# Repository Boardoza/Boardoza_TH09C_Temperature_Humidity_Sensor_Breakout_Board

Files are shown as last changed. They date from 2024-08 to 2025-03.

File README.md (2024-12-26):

# Boardoza TH09C Temperature Humidity Sensor Breakout Board
The TH09C Digital Temperature and Humidity Sensor Breakout Board offers reliable environmental monitoring with high accuracy and low power consumption. Featuring the TH09C sensor, this board provides precise digital temperature and humidity readings via an I<sup>2</sup>C interface. Its fast response time and high repeatability make it ideal for use in HVAC systems, weather stations, and other applications where environmental data is critical. 

### [Click here to purchase!](https://www.ozdisan.com/maker-and-iot-products/boardoza/boardoza-modules/BOARDOZA-TH09C/1206510)

|Front Side|Back Side|
|:---:|:---:|
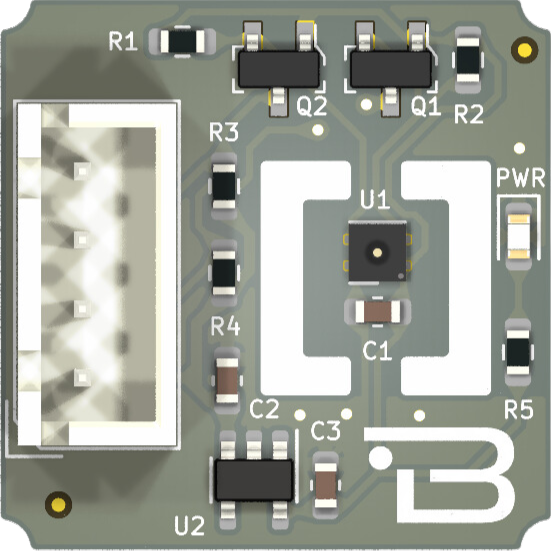
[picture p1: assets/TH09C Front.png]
TH09C Front
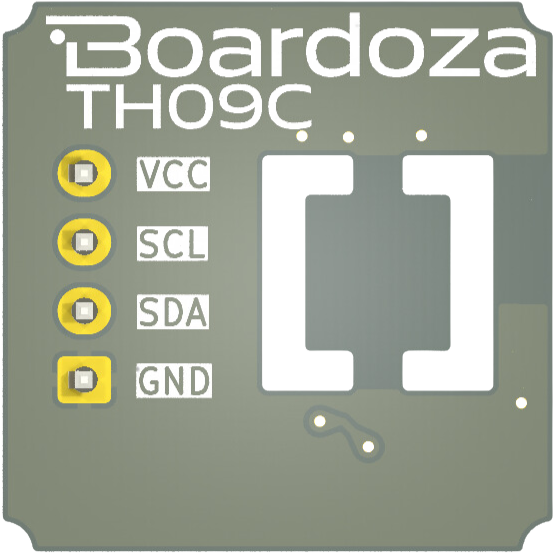
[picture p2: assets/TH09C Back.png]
TH09C Back
| | |

---
## Key Features
- Ultra-Accurate Sensing: Temperature sensor with ±0.15°C accuracy and relative humidity sensor with typical ±2.0%RH accuracy.
- Wide Sensing Range: Supports temperature measurement from –40°C to 100°C and humidity from 0% to 100%.
- Digital Output: Provides digital temperature and humidity readings via TTL I2C interface for easy integration.
- Low Power Consumption: Optimized for battery-operated devices with minimal energy usage.
-Compact Design: Small form factor suitable for a wide range of environmental monitoring applications.

---

## Technical Specifications

**Input Voltage:**	2V - 5.5V

**Voltage Input Type:**	Molex 4 pin 2.50mm header

**Interface:** I<sup>2</sup>C  

**Functions:**	Temprature and Humidity Sensor

**Temperature Accuracy:** ±0.15°C  

**Humidity Accuracy:** Typical ±2.0% RH  

**Measurement Range:**	 -40°C ~ +100°C

**Operating Humidity:** 0% to 100% RH  

**Operating Temperature:**	-40°C ~ +100°C

**Board Dimensions:**	20mm x 20mm

---
## Board Pinout
| (J1) Pin Number | Pin Name | Description |
|:---:|:---:| --- |
| 1 | VCC | Power Supply |
| 2 | SCL | I<sup>2</sup>C Serial Clock Pin |
| 3 | SDA | I<sup>2</sup>C Serial Data Pin|
| 4 | GND | Ground|

---
## Board Dimensions

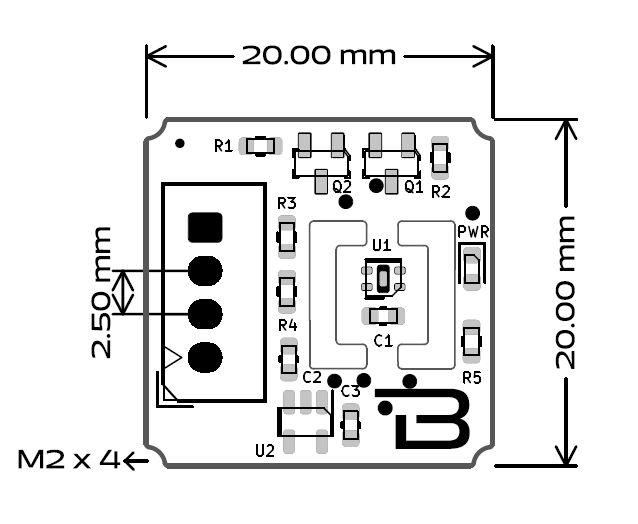
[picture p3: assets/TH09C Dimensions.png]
TH09C Dimension


---
## Step Files

[Boardoza TH09C.step]( ./assets/TH09C%20Step.step)

---
## Datasheet

[Boardoza TH09C Datasheet.pdf](./assets/TH09C%20Datasheet.pdf)

---
## Version History
- V1.0.0 - Initial Release

---
## Support
- If you have any questions or need support, please contact support@boardoza.com

---
## License

Shield: [][cc-by-sa]

This work is licensed under a [Creative Commons Attribution-ShareAlike 4.0 International License][cc-by-sa].

[][cc-by-sa]

[cc-by-sa]: http://creativecommons.org/licenses/by-sa/4.0/
[cc-by-sa-image]: https://licensebuttons.net/l/by-sa/4.0/88x31.png
[cc-by-sa-shield]: https://img.shields.io/badge/License-CC%20BY--SA%204.0-lightgrey.svg

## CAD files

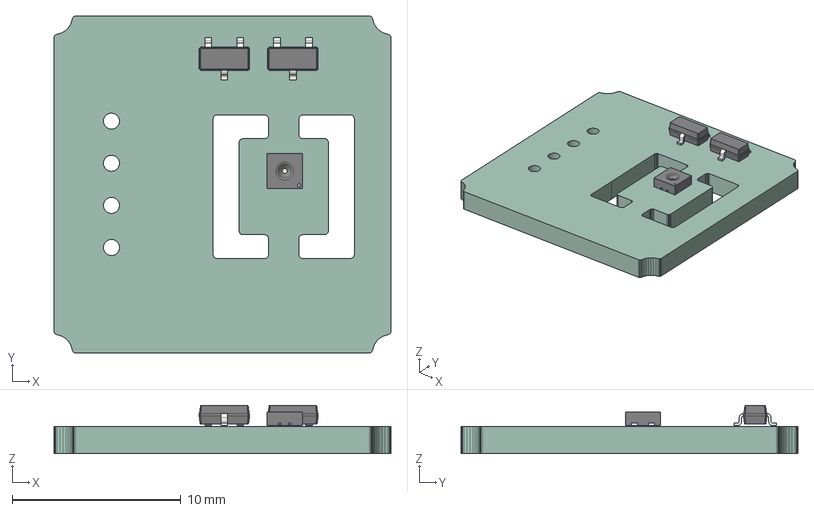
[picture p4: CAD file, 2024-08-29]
assets/TH09C Step.step
20.0 x 20.0 x 2.85 mm
SHTC3
SOT_23 x 2
_autosave-TH09C_TEMP_SENSOR PCB

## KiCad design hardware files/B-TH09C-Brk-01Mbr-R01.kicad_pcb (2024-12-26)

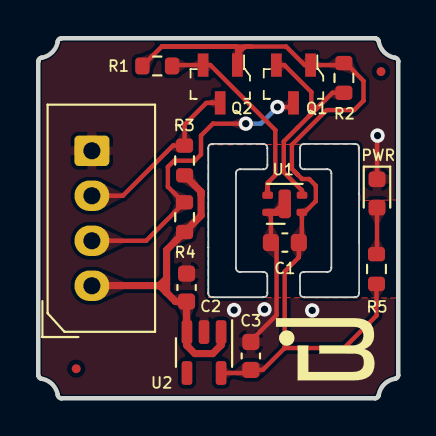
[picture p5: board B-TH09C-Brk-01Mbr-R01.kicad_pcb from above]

Board: 2 copper layers, 20.0 x 20.0 mm, 14 parts (0 on the bottom side), 8 nets.

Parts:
C1: 100nF; C_0603_1608Metric
C2, C3: 1uF; C_0603_1608Metric
J1: MOLEX_CONNECTOR_1X4; 2317-04S_1x04_P2.50mm_Vertical
PWR: LED POWER; LED_0603_1608Metric
Q1, Q2: 2N7002_R1_00001; SOT-23-3
R1, R2, R3, R4, R5: 10K; R_0603_1608Metric
U1: TH09C
U2: TLV73333PDBVR; SOT-23-5

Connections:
+3V3: C1.1, C3.1, Q1.1 (G), Q2.1 (G), R1.1, R2.1, R5.1, U1.1 (VDD), U2.5 (OUT)
GND: C1.2, C2.2, C3.2, J1.4, PWR.1 (K), U1.4 (VSS), U1.5 (NC), U2.2 (GND)
unnamed: PWR.2 (A), R5.2
unnamed: Q1.2 (S), R2.2, U1.2 (SCL)
unnamed: Q2.2 (S), R1.2, U1.3 (SDA)
SCL: J1.2, Q1.3 (D), R4.2
SDA: J1.3, Q2.3 (D), R3.2
VCC: C2.1, J1.1, R3.1, R4.1, U2.1 (IN), U2.3 (EN)

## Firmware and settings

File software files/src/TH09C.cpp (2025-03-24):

/*!
 *  @file TH09C.cpp
 *
 *  @mainpage TH09C is a low cost temperature/humidity sensor.
 *
 *  @section intro_sec Introduction
 *
 *  This is a library for Boardoza TH09C low cost temperature/humidity sensors.
 *
 *  @section author Author
 *
 *  Written by Boardoza.
 *
 *  @section license License
 *
 *  MIT license, all text above must be included in any redistribution
 */


#include "TH09C.h"
#include <Arduino.h>

/** @brief begin
*          Starts the I2C connection and setup sensor pins.
* @param frequency I2C speed in KHz.
*/ 

TH09C::TH09C() {

}

void TH09C::begin() {
  Wire.begin();  // Setting I2C speed.
  delay(100);

  uint8_t TH09_Ctrl = readByteOneReg(TH09_Address, SYS_CTRL);
  if (!TH09_Ctrl) {
    uint8_t TH09_Low_Power = 0;  // Failed to read control register, low power mode inactive
  } else {
    while (writeByteOneReg(TH09_Address, SYS_CTRL, 0x00) != 0) {
      // Activating low power mode, waiting until the process is complete...
    }
    uint8_t TH09_Low_Power = 1;  // Low power mode successfully activated
  }

  uint8_t TH09_Status = readByteOneReg(TH09_Address, SYS_STAT);

  uint8_t TH09_SensRun = readByteOneReg(TH09_Address, SENS_RUN);
  if (!TH09_SensRun) {
    while (writeByteOneReg(TH09_Address, SENS_RUN, 0x03) != 0) {
      // Activating the sensor, waiting until the activation process is complete...
    }
  }
  
  uint8_t TH09_SensStart = readByteOneReg(TH09_Address, SENS_START);
  if (!TH09_SensStart) {
    while (writeByteOneReg(TH09_Address, SENS_START, 0x03) != 0) {
      // Initializing the sensor, waiting until initialization is complete...
    }
  }
}

/**
 * @brief Reads the temperature and humidity values from the TH09 sensor.
 *
 * This function reads the temperature and humidity values from the TH09 sensor
 * using the `readMultiBytesOneReg` function. It converts the raw temperature value
 * from Fahrenheit to Celsius and calculates the relative humidity as a percentage.
 * The results are stored in the `temperature` and `humidity` variables passed by reference.
 *
 * @param temperature Reference to a float variable to store the temperature in Celsius.
 * @param humidity Reference to a float variable to store the relative humidity in percentage.
 */


void TH09C::readTempHum(float& temperature, float& humidity) {
  uint8_t TH09_Temp_Array[2];
  readMultiBytesOneReg(TH09_Address, T_VAL, TH09_Temp_Array, 2);

  float TH09_Temp =  TH09_Temp_Array[1] << 8 | TH09_Temp_Array[0];
  TH09_Temp = (TH09_Temp) / 64;            // Fahrenheit to Kelvin   
  temperature = TH09_Temp - 273.15;        // Kelvin to Celsius

  uint8_t TH09_Hum_Array[2];
  readMultiBytesOneReg(TH09_Address, H_VAL, TH09_Hum_Array, 2);
  uint16_t TH09_Hum = TH09_Hum_Array[1] << 8 | TH09_Hum_Array[0];
  humidity = (float)TH09_Hum / 512;        // Relative humidity (in %)
}

/**
 * @brief Reads the temperature value from the TH09 sensor.
 *
 * This function reads the temperature value from the TH09 sensor
 * using the `readMultiBytesOneReg` function. It converts the raw temperature value
 * from Fahrenheit to Celsius.
 * The results are stored in the `temperature` and variables passed by reference.
 *
 * @param temperature Reference to a float variable to store the temperature in Celsius.
 */

void TH09C::readTemp(float& temperature) {
  uint8_t TH09_Temp_Array[2];
  readMultiBytesOneReg(TH09_Address, T_VAL, TH09_Temp_Array, 2);

  float TH09_Temp =  TH09_Temp_Array[1] << 8 | TH09_Temp_Array[0];
  TH09_Temp = (TH09_Temp) / 64;            // Fahrenheit to Kelvin   
  temperature = TH09_Temp - 273.15;        // Kelvin to Celsius
}

/**
 * @brief Reads the humidity value from the TH09 sensor.
 *
 * This function reads the humidity value from the TH09 sensor
 * using the `readMultiBytesOneReg` function. It calculates the relative humidity as a percentage.
 * The results are stored in the `temperature` and `humidity` variables passed by reference.
 *
 * @param temperature Reference to a float variable to store the temperature in Celsius.
 */

void TH09C::readHum(float& humidity) {
  uint8_t TH09_Hum_Array[2];
  readMultiBytesOneReg(TH09_Address, H_VAL, TH09_Hum_Array, 2);
  uint16_t TH09_Hum = TH09_Hum_Array[1] << 8 | TH09_Hum_Array[0];
  humidity = (float)TH09_Hum / 512;        // Relative humidity (in %)
}


/**
 * @brief Converts a temperature value to different units.
 *
 * This function converts a temperature value to different units based on the specified unit parameter.
 * The supported unit values are "K" (Kelvin) and "F" (Fahrenheit). If an invalid unit is specified,
 * the function returns the original temperature value without any conversion.
 *
 * @param temperature The temperature value to be converted.
 * @param unit The unit to which the temperature should be converted. Valid values are "K" and "F".
 *
 * @return The converted temperature value.
 * 
 * @note This function assumes that the input temperature is in Celsius.
 *       If the temperature is in a different unit, convert it to Celsius before calling this function.
 */

float TH09C::celciusConverter(float& temperature, char unit) {
  if (unit == 'K') {           // Kelvin
    return temperature + 273.15;
  } else if (unit == 'F') {    // Fahrenheit
    return (temperature * 9/5) + 32;
  } else {
    // Returns the original temperature value if an invalid unit is specified.
    return temperature;
  }
}

/**
 * @brief Converts a temperature value from Kelvin to different units.
 *
 * This function converts a temperature value from Kelvin to different units based on the specified unit parameter.
 * The supported unit values are "C" (Celsius) and "F" (Fahrenheit). If an invalid unit is specified,
 * the function returns the original temperature value without any conversion.
 *
 * @param temperature The temperature value in Kelvin to be converted.
 * @param unit The unit to which the temperature should be converted. Valid values are "C" and "F".
 *
 * @return The converted temperature value.
 *
 * @note This function assumes that the input temperature is in Kelvin.
 *       If the temperature is in a different unit, convert it to Kelvin before calling this function.
 */

float TH09C::kelvinConverter(float& temperature, char unit) {
  if(unit == 'C') {
    return temperature - 273.15;
  } else if (unit == 'F') {
    return (temperature * 9/5) - 459.67;
  } else {
    // Returns the original temperature value if an invalid unit is specified.
    return temperature;
  }
}
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

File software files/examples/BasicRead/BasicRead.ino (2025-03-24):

#include "TH09C.h"

TH09C th09cSensor;

void setup() {
  Serial.begin(115200);
  th09cSensor.begin();
}

void loop() {
  float temperature, humidity;

  th09cSensor.readTempHum(temperature, humidity);

  Serial.print("Temperature: ");
  Serial.print(temperature);
  Serial.print(" °C ");

  Serial.print("Humidity: ");
  Serial.print(humidity);
  Serial.println(" %");

  delay(100);
}

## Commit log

2024-08-29 Initial commit for TH09C breakout board.
    [TH09C Step.step]
2024-12-26 Add Gerber files and update README for TH09C breakout board
    [B-TH09C-Brk-01Mbr-R01-B_Cu.gbl, B-TH09C-Brk-01Mbr-R01-B_Mask.gbs, B-TH09C-Brk-01Mbr-R01-B_Paste.gbp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]
